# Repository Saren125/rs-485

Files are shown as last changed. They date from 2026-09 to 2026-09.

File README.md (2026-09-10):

rs-485 3d

# RS-485 MCU Load Control Module / Модуль Управления Нагрузкой с Интерфейсом RS-485 на МК
[English](#english) | [Русский](#русский)

---

## English

### Project Overview
A robust, industrial-grade microcontroller module designed for load control and communication via an isolated **RS-485** interface. The heart of the system is an **STM32F103** MCU, complemented by a fully isolated RS-485 transceiver. 

The module features a highly reliable dual-stage power architecture and strict isolation between high-power switching nodes and sensitive digital logic to ensure flawless operation in high-noise industrial environments.

> **Status:** Fully completed.
### Technical Specifications
* **Microcontroller:** STMicroelectronics **STM32F103C8T6** (ARM Cortex-M3)
* **Interface:** Isolated RS-485 using **ADM2587EBRWZ** (Features integrated signal and power galvanic isolation).
* **Power Supply Architecture (Dual-Stage):**
  1. *Stage 1 (Buck):* **LM2596S-5.0** high-efficiency switching regulator drops input voltage down to 5.0V.
  2. *Stage 2 (LDO):* **AMS1117-3.3** linear regulator provides ultra-low-noise 3.3V power directly to the MCU core.
* **Load Rating:** Up to **2A** control capacity.
* **CAD Software:** Altium Designer

### Design Strategy & Hardware Features
* **Galvanic Isolation:** The ADM2587E transceiver fully separates the RS-485 bus from the internal digital logic, protecting the MCU from ground loops, high-voltage surges, and communication line faults.
* **Grounding Strategy:** Rigid separation between the digital ground (`GND_Digital`) and high-current/power ground (`GND_Power`) to shield the analog/digital circuitry from switching noise.
* **Dual-Stage Regulation:** Combining a switching buck with a linear LDO guarantees maximum power efficiency without sacrificing the voltage stability required for the ARM microcontroller.

---

## Русский

### Обзор проекта
Надежный модуль управления нагрузкой промышленного класса с поддержкой обмена данными по изолированному интерфейсу **RS-485**. Устройство построено на базе микроконтроллера **STM32F103** и специализированного трансивера с полной гальванической развязкой сигналов и питания.

В модуле реализована двухступенчатая топология питания и жесткое разделение силовых и сигнальных цепей для стабильной работы в условиях высокого уровня индустриальных помех.

> **Текущий статус:** Готов

### Технические характеристики
* **Микроконтроллер:** STMicroelectronics **STM32F103C8T6** (ARM Cortex-M3)
* **Интерфейс связи:** Изолированный RS-485 на базе **ADM2587EBRWZ** (микросхема со встроенной гальванической развязкой сигнальных линий и линий питания).
* **Архитектура питания (Двухступенчатая):**
  1. *1-я ступень:* Высокоэффективный импульсный понижающий регулятор **LM2596S-5.0** (понижение входного напряжения до 5.0В).
  2. *2-я ступень:* Линейный стабилизатор (LDO) **AMS1117-3.3** (формирование чистых 3.3В без импульсных помех для питания ядра МК).
* **Коммутируемая нагрузка:** До **2А**.
* **Программное обеспечение:** Altium Designer.

### Особенности схемотехники и трассировки
* **Гальваническая развязка:** Применение трансивера ADM2587E изолирует шину RS-485 от внутренней логики устройства, защищая МК от контуров заземления (ground loops), высоковольтных скачков и повреждений линии связи.
* **Разделение земель:** Цифровая (сигнальная) земля и силовая земля нагрузки строго разделены, что исключает влияние импульсных токов коммутации на стабильность работы цифровой части.
* **Двухступенчатая стабилизация:** Связка из импульсного buck-регулятора и линейного LDO обеспечивает высокий общий КПД системы при сохранении идеальной стабильности напряжения питания для ARM-ядра.

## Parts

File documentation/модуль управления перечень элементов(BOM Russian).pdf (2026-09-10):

Изм. Лист | № докум. | Подп. | Дата
| Разраб. | | | Модуль управления нагрузкой Перечень элементов | Лит. | Лист | Листов
Пров. | | | | | | 1 2
Н.контр. Инв. № подл. Подп. и дата Взам. инв. № Инв. № дубл. Подп. и дата | Утв. Справ. № Перв. примен. | Конденсаторы
С1 | Конденсатор электролитический 680мкФ, 50В, 105°C, 20% JRB1H681M05001300200000B JB | 1
C2 | Конденсатор керамический 0.1мкФ X7R 50В 10% 0603 GCM188R71H104KA57D Murata | 1
C3 | Конденсатор электролитический 220мкФ 25В 105°C 20% JRB1E221M03500800120000B JB | 1
C4 | Конденсатор танталовый 10мкФ 10В 10% SMD A TECAP10/10VA10 TECAP | 1
C5 | Конденсатор танталовый 22мкФ 10В 10% SMD B 9000502415 TECAP | 1
C6,C7 | Конденсатор керамический 22пФ NP0 50В 5% 0603 GRM1885C1H220JA01D JAGEO | 2
C8-C15 | Конденсатор керамический 0.1мкФ X7R 16В 10% 0603 GRM188R71C104KA01D MURATA | 8
C16,C17 Конденсатор керамический 0.01мкФ X7R 16В 10% 0603 CC0603KRX7R7BB103 YAGEO | | 2
C18 | Конденсатор керамический 10мкФ X5R 16В 10% 0603 CC0603KRX5R7BB106 YAGEO | 1
C19,C20 Конденсатор керамический 0.1мкФ X7R 16В 10% 0603 GRM188R71C104KA01D MURATA | | 2

Микросхемы

D1 | Микросхема стабилизатора напряжения импульсного 5В 3А 150кГц TO-263 LM2596S-5.0 UMW | 1
D2 | Микросхема стабилизатора напряжения линейного +3.3В, 0.8А SOT-223 AMS1117-3.3 Advanced Monolithic Systems | 1
D3 | Микросхема микроконтроллера 32-Бит Cortex-M3 72МГц 64КБ Flash USB CAN LQFP-48 STM32F103C8T6 STMicroelectronics | 1
D4 | Микросхема приемопередатчика RS-485 SOIC-20 ADM2587EBRWZ-REEL7 Analog Devices | 1

Реле

K1,K2 | Реле IM03GR SMD TE Connectivity | 2
| Фильтры
L1 | Катушка индуктивности 47мкГн 4.6А SMD SPRH127-470M SCE | 1
L2 | Бусина ферритовая 600 Ом 500 мА 1,5 Ом ±25% 0603 FCM1608KF-601T05 TAI-TECH | 1

Поз.
обозначение
Наименование | Кол. Примечание
Копировал | Формат A4

Лист

Резисторы

R1, R2,R3 Резистор 10 кОм 0.1% 0.1 Вт 0603 RT0603BRB0710KL YAGEO | | 3
R4 | Резистор 120 Ом 0.1% 0.1 Вт 0603 RC0603FR-07120RL YAGEO | 1
R5,R6 | Резистор 10 кОм 0.1% 0.1 Вт 0603 RT0603BRB0710KL YAGEO | 2

Диоды

VD1,VD2 Диод Шоттки 40V 3A SMC SS34 Taiwan Semiconductor | 2
VD3,VD4 Диод защитный SMC SMCJ12CA LittleFuse | 2
VD5,VD6 Диод импульсный 0.15А 100В SOD-123 1N4148W Sunmate Electronics | 2

Транзисторы

VT1,VT2 Транзистор полевой N-канальный 60В 115мА SOT-23 2N7002 UMW 2

Соединители

X1 | Клеммник винтовой 2-контактный 5мм прямой L-KLS2-300-5.00-02P-2S KLS | 1
X2 | Вилка штыревая 2.54мм 1x4pin прямая DS-1021-1x4 Zhenqin | 1
X3 | Вилка штыревая 2.54мм 1x2pin прямая DS1021-1x2 Zhenqin | 1
Изм. Лист X4,X5 Клеммник винтовой 3-контактный 5мм прямой L-KLS2-300-5.00-03P-2S KLS | № докум. Подп. Дата | 2 | 2 Инв. № подл. Подп. и дата Взам. инв. № Инв. № дубл. Подп. и дата

Резонаторы пьезоэлектрические

Z1 | Резонатор кварцевый 8 мГЦ 2520 SJK-7U-8.000-12-30-150-C-100 SJK | 1

Поз.
обозначение
Наименование | Кол. Примечание
Копировал | Формат A4

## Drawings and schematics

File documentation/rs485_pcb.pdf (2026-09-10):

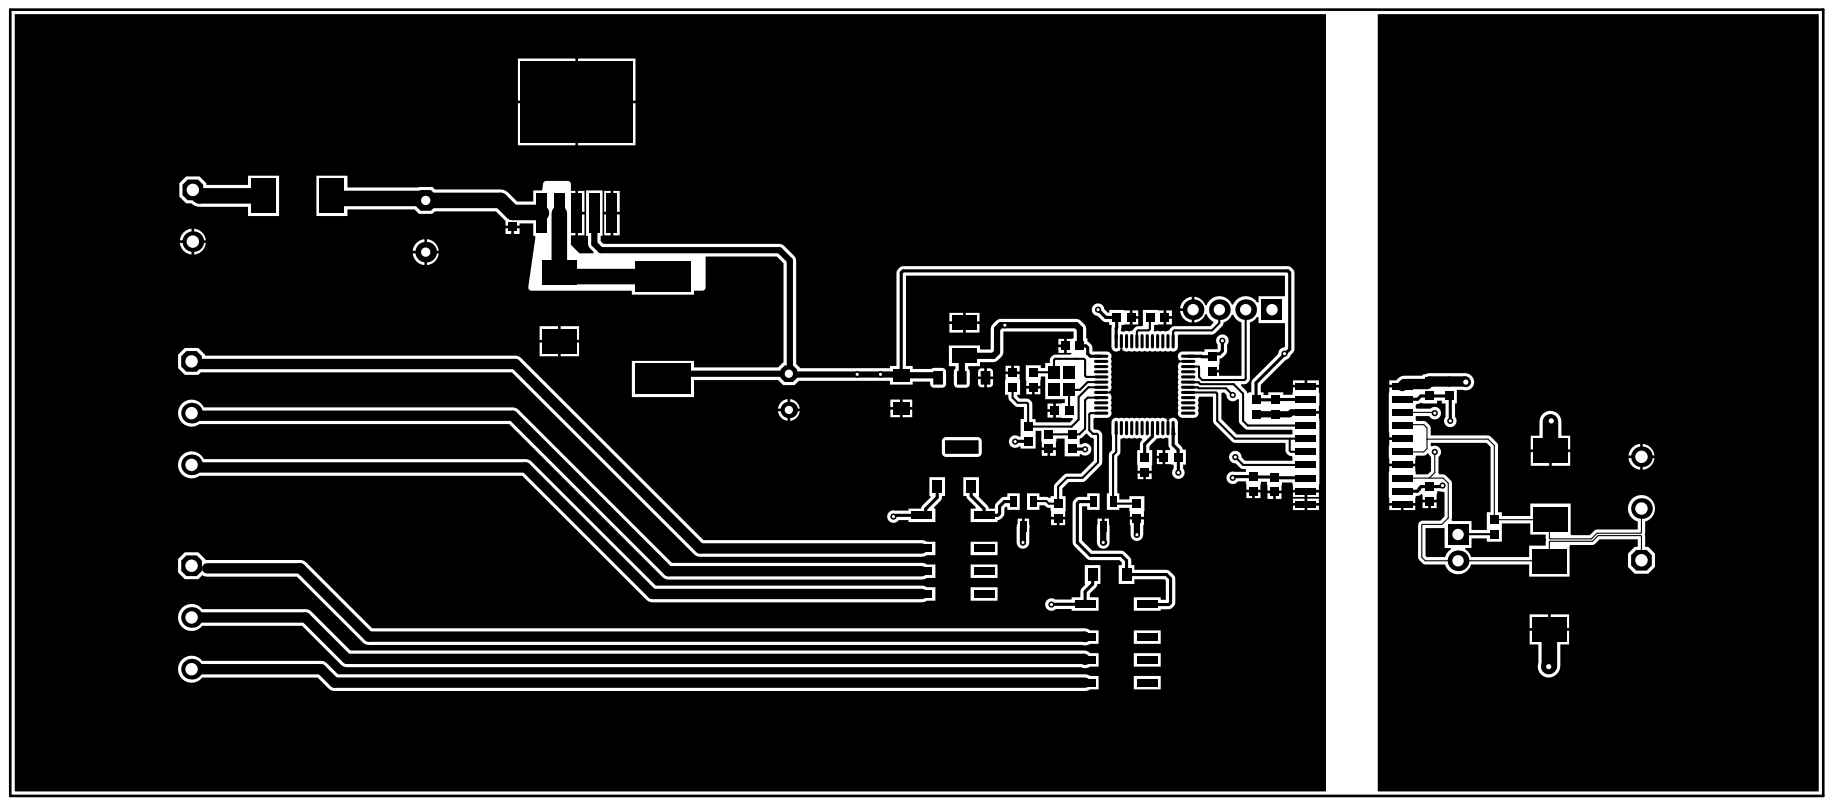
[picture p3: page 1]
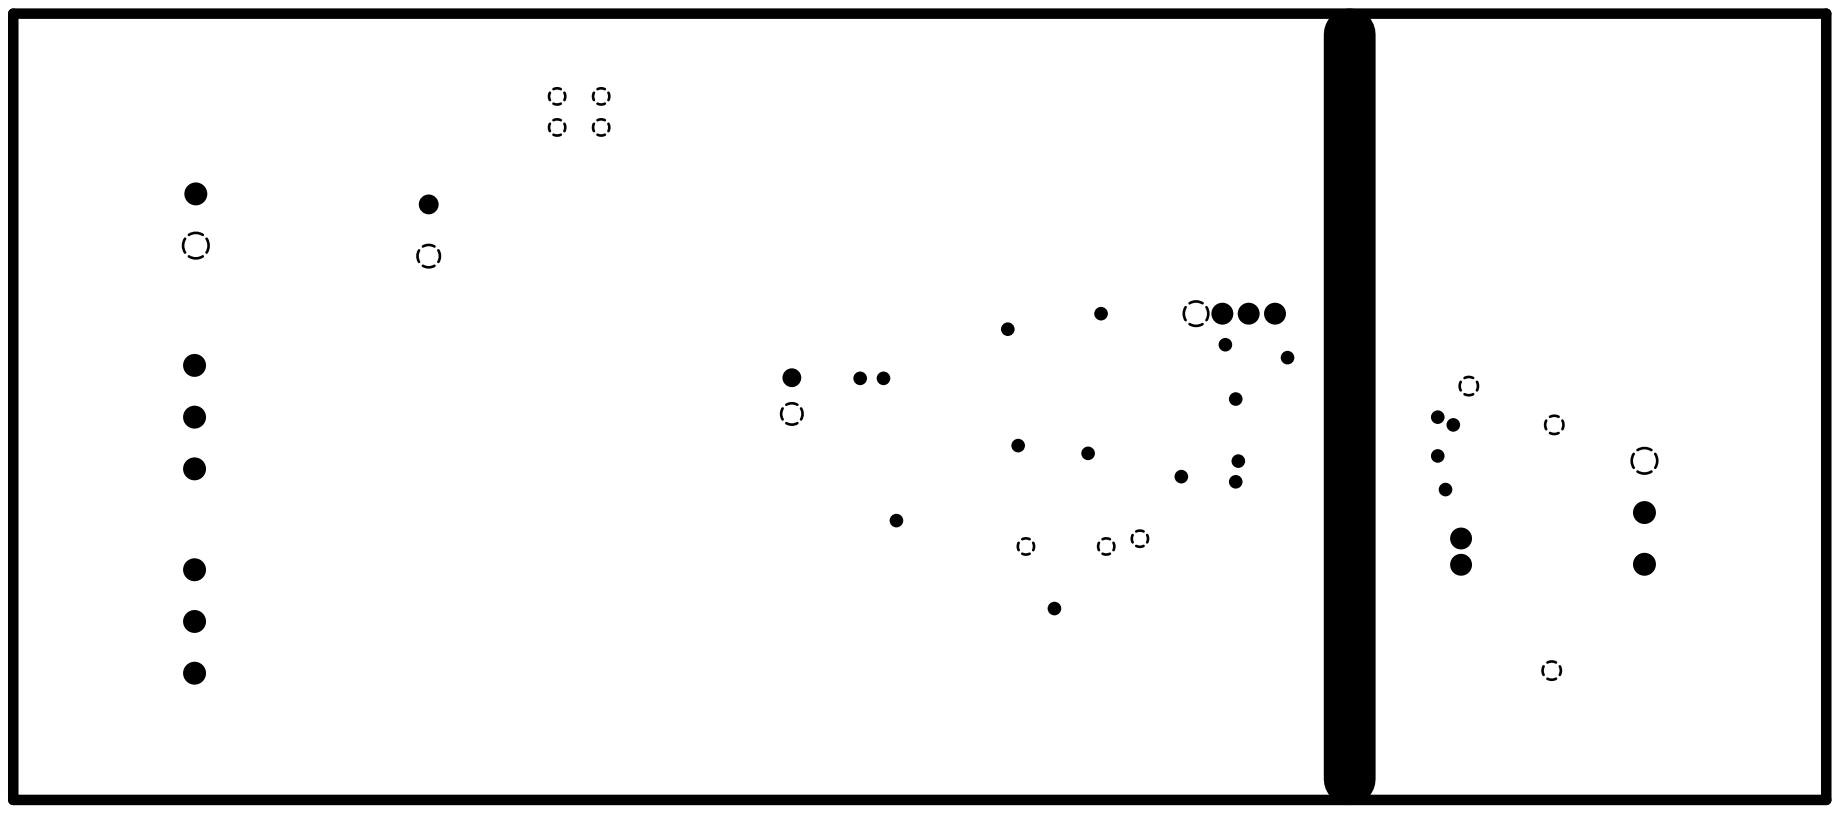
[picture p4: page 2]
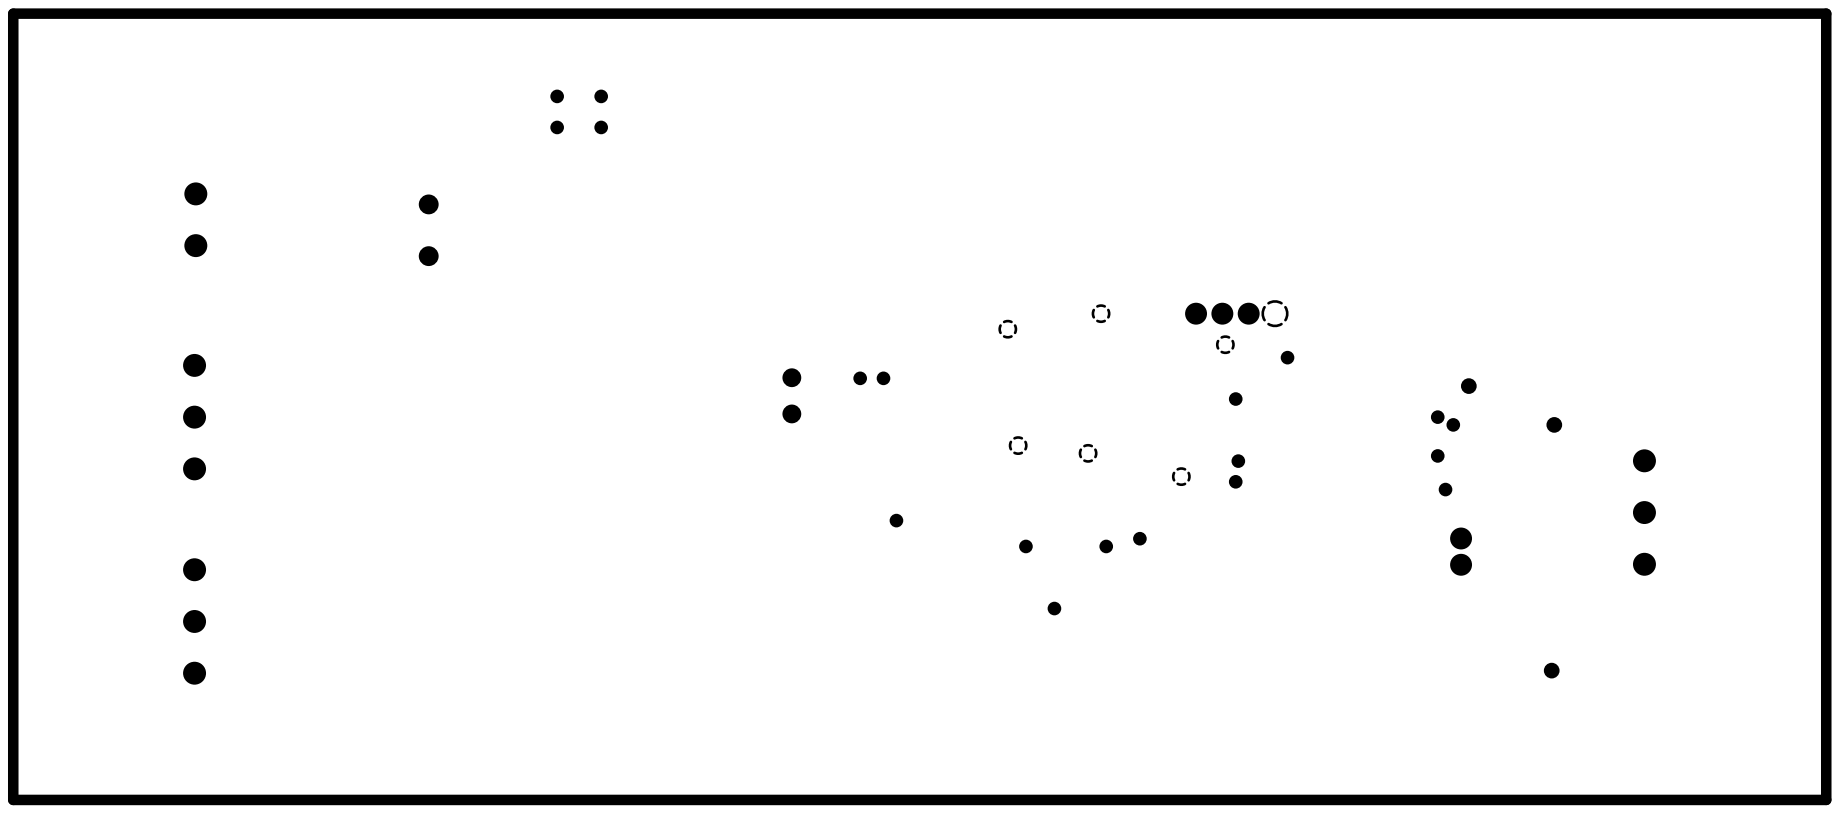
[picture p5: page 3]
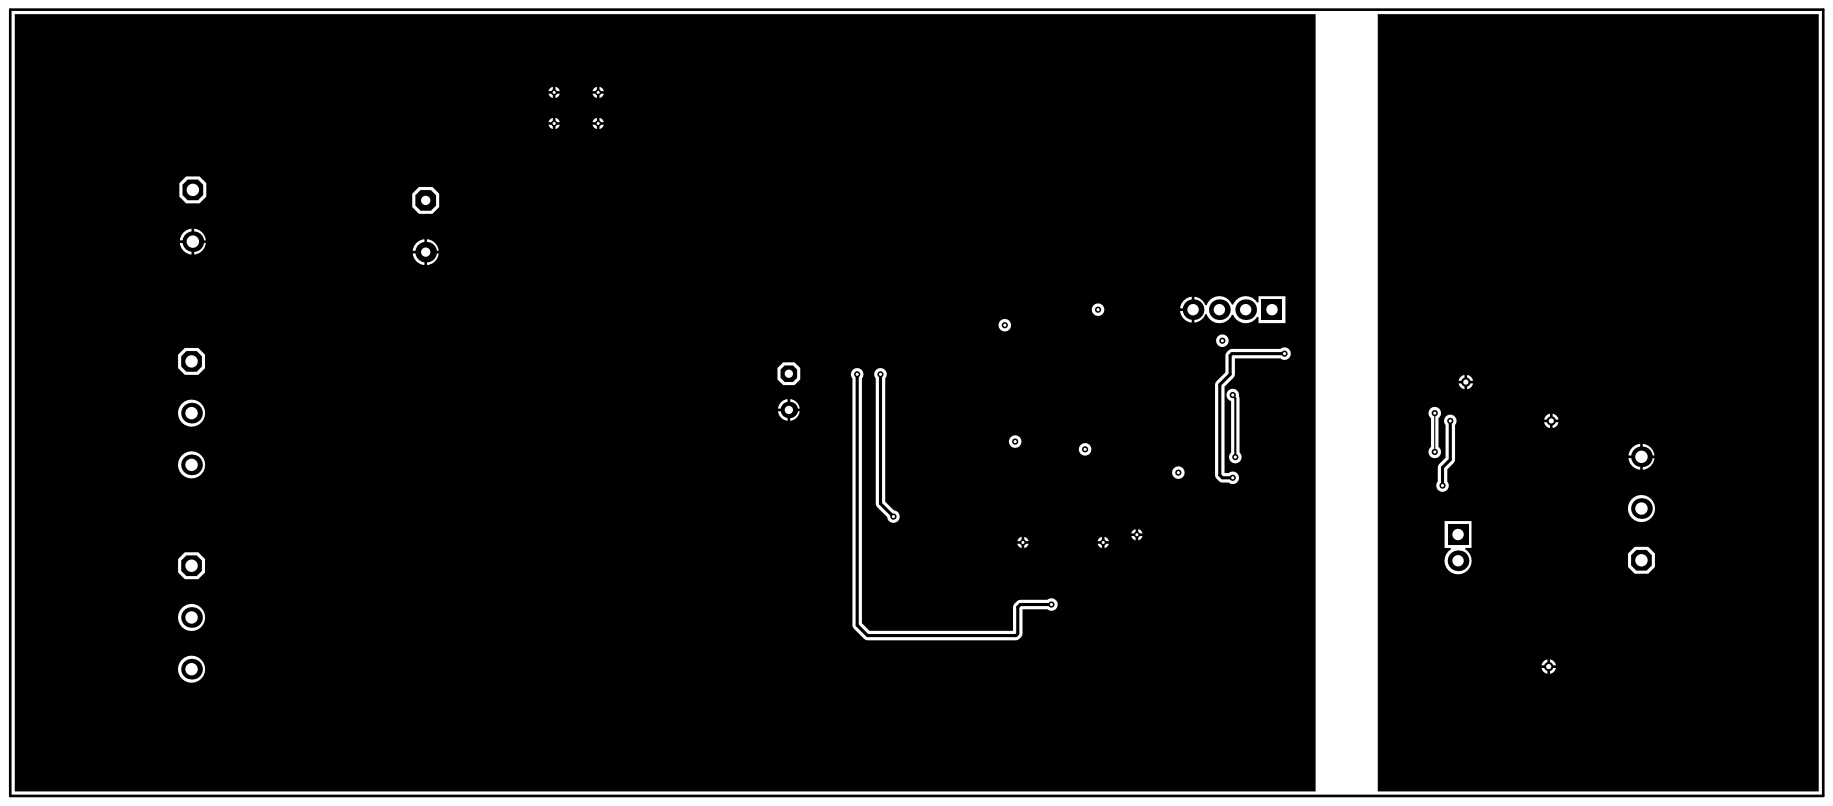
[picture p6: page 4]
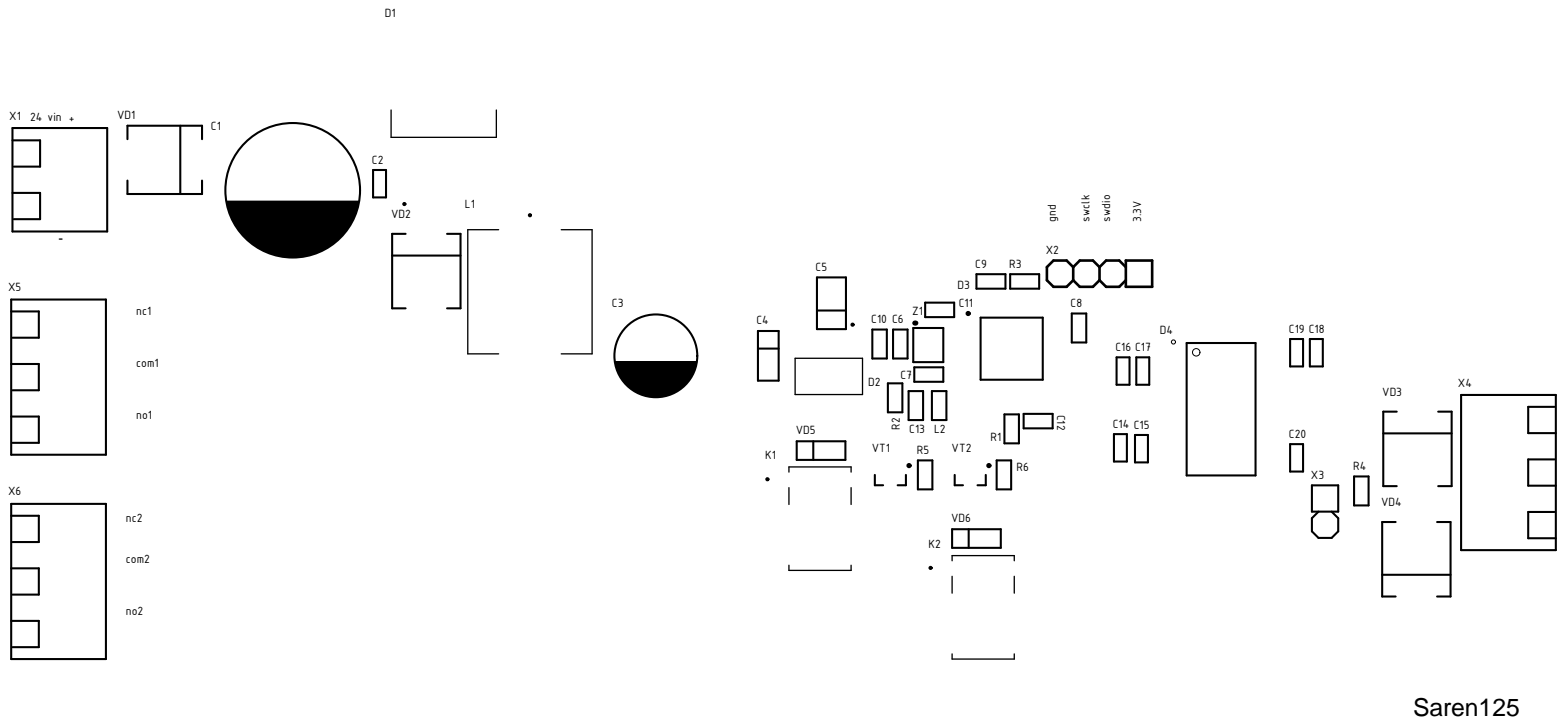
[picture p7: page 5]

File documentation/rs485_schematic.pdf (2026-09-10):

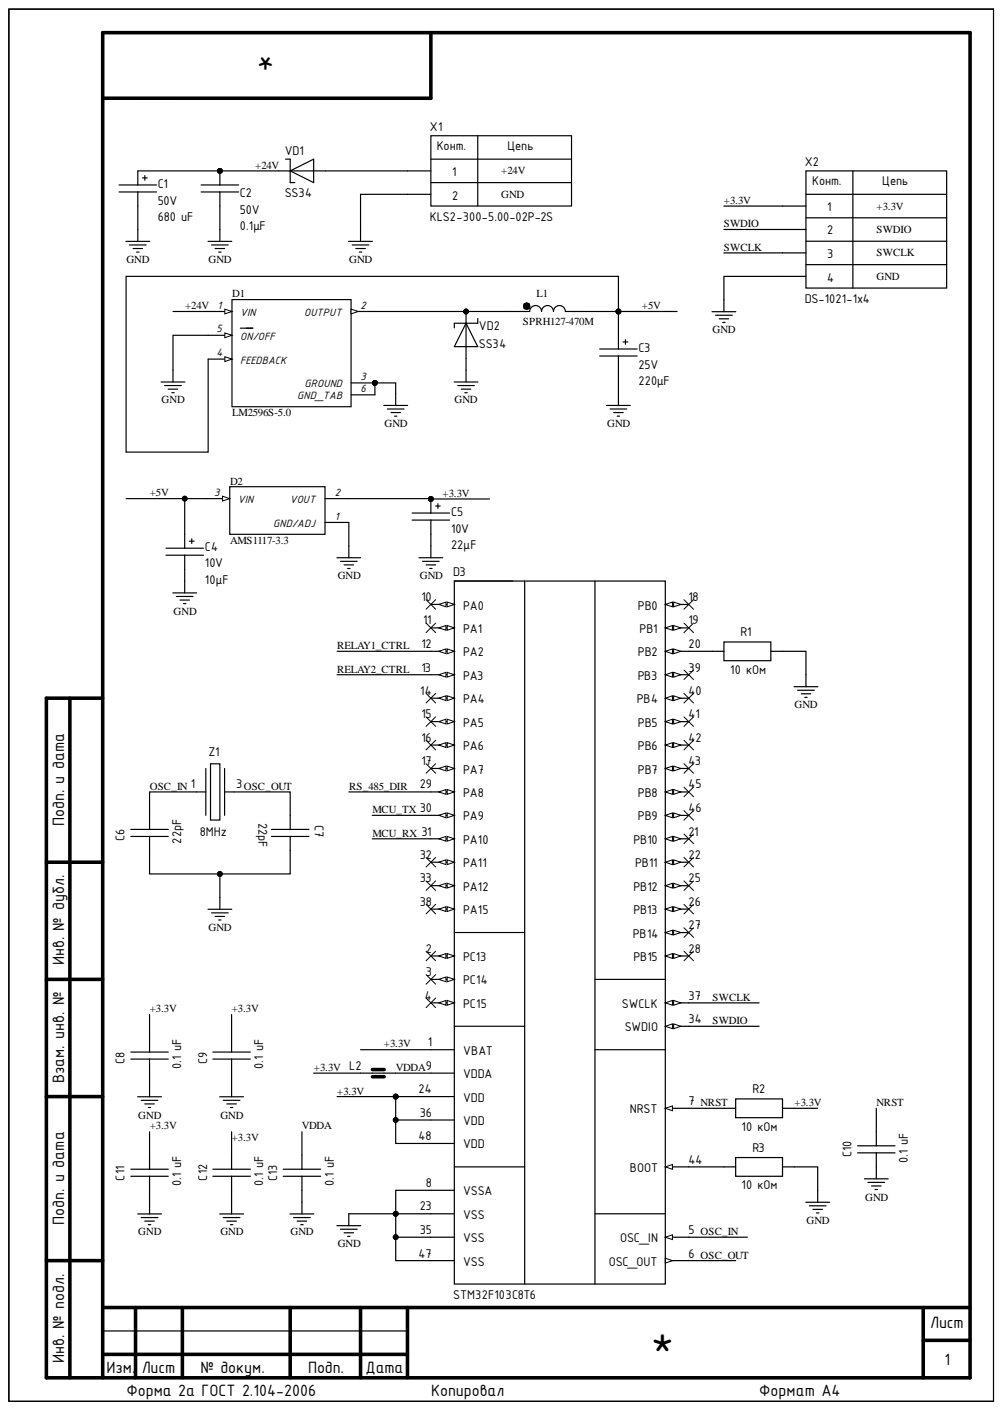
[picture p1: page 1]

X1
Конт. | Цепь

2 | GND

2 | SWDIO

3 | SWCLK

4 | GND

Инв. № подл. Подп. и дата Взам. инв. № Инв. № дубл. Подп. и дата

VDD 24

VDD 48 | R3

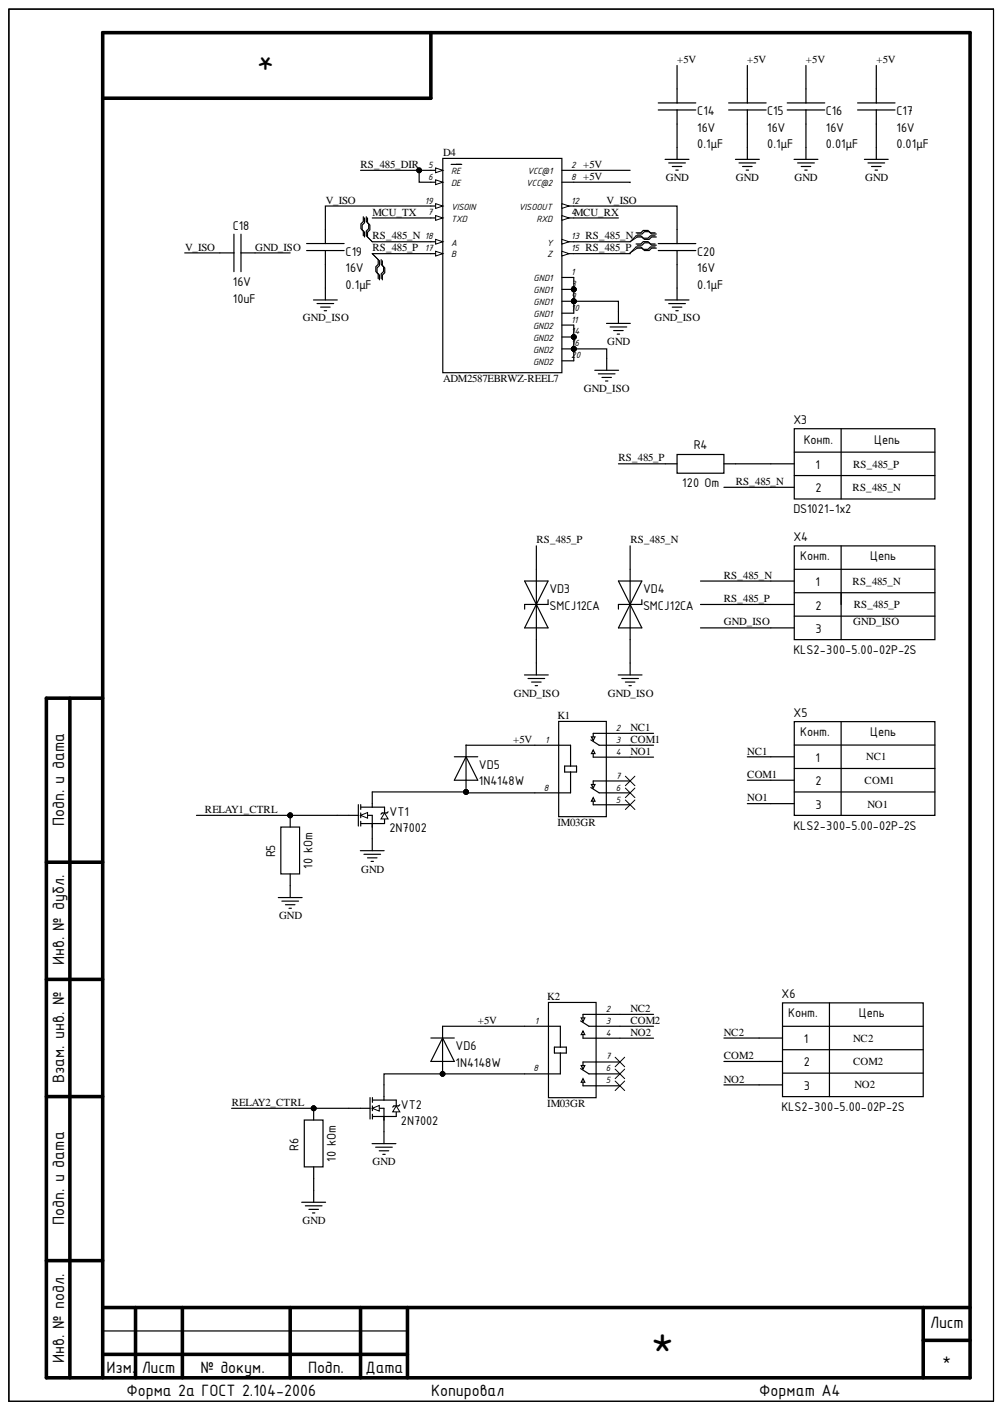
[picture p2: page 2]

Конт. | Цепь

2 | RS_485_P
3 | GND_ISO

Инв. № подл. Подп. и дата Взам. инв. № Инв. № дубл. Подп. и дата

2 | COM2
